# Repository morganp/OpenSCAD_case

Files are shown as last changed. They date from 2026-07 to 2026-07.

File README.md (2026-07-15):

# OpenSCAD_case

Parametric case/box library, plain OpenSCAD, no external libraries beyond the
[OpenSCAD_hinge](https://github.com/morganp/OpenSCAD_hinge) dependency (auto-fetched by
[OpenSCAD-gui](../OpenSCAD-gui) via its `// @github:` tag). Loadable standalone in real
OpenSCAD and in the browser.

## hinged_box — two-tray hinged box with pinned hinges and a snap latch

A body tray and a lid tray joined by real pinned hinges across the back seam, with an
alignment lip on the body rim and a snap latch on the front. Two printed parts, no supports;
each part carries its own fused hinge leaf, and a pin dropped through the knuckles finishes
the assembly. Far more robust than a living/flex hinge, and the pin is replaceable if it
ever wears.

| Print pose | Closed (assembly check) |
|---|---|
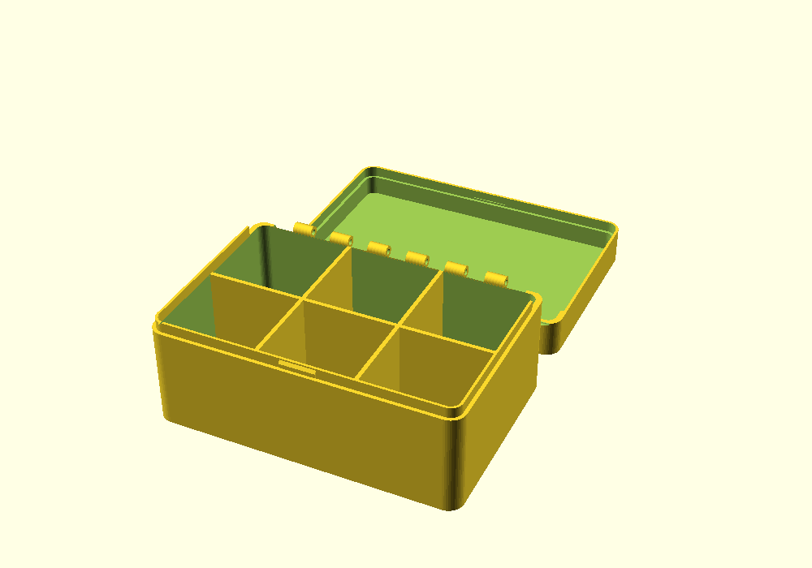
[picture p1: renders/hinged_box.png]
hinged_box print pose
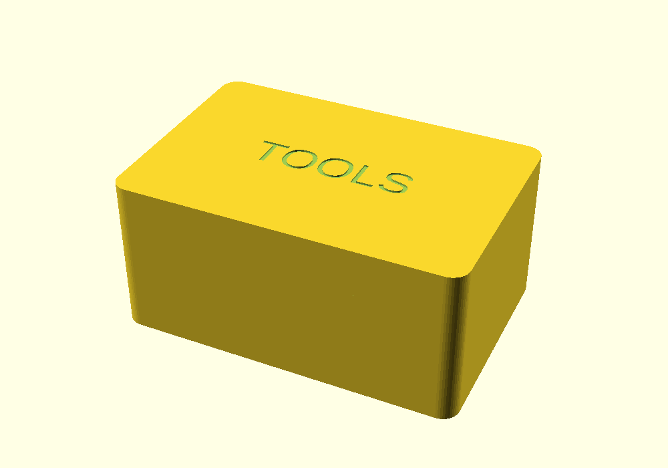
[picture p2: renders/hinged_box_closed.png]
hinged_box closed
|  |  |

**[▶ Open in SCAD Studio](https://lizard-spock.co.uk/openscad-gui/?github=morganp/OpenSCAD_case/examples/hinged_box_demo.scad)** —
view this example in the browser, no install; the library (and its hinge dependency) load automatically.

```openscad
include <case_library.scad>

hinged_box(
    length = 120, width = 80, height = 40,
    lid_depth = 15,
    div_x = 2, div_y = 1,
    lid_text = "TOOLS"
);
```

### Hinge types

| `hinge_type` | Hinge | Pin |
|---|---|---|
| `"piano"` (default) | One continuous knuckle hinge across the back seam — even load spread, sturdiest | 1.75mm filament offcut |
| `"knuckle"` | `hinge_count` discrete knuckle hinges — lighter, classic look | 1.75mm filament offcut |
| `"crate"` | Chunky raised-lug crate hinges, lid opens past 180° — the rugged/ammo-box look | 4mm rod, or the printed pins emitted beside the parts |
| `"flush"` | Fully hidden hinge: pivot buried mid-wall, knuckle OD = wall thickness, zero protrusion; works down to 2mm walls; lid opens flat to 180° | 0.8mm rod/wire, slid in along the seam; far end blind, printed cap glues into the first knuckle |

The hinge geometry itself comes from
[OpenSCAD_hinge](https://github.com/morganp/OpenSCAD_hinge)'s `piano_hinge` /
`knuckle_hinge` / `crate_hinge` / `flush_knuckle_hinge`, emitted one leaf at a time
(`parts="leaf1"/"leaf2"`) so each printed part gets its own fused leaf.

### Flush (hidden) hinge variation

`hinge_type="flush"` buries the pivot in the middle of the back wall: the knuckles are sized
to the wall thickness and nothing protrudes past the outer face — the hinge reads as a plain
seam with a knuckle line inside a cove. Works down to 2mm walls (2mm knuckles). The hinge is
`flush_knuckle_hinge`: each leaf plate is as thick as the wall and runs right up to the axis,
with a scallop along its inner edge that nests the other leaf's knuckles at close radial
tolerance, so it closes flat and the lid opens flat to a full 180°. Outside the hinge span
the rims still carry a cove relief to swing past the buried axis.

The pin is a 0.8mm rod or wire (`pin_d` auto). The axis line runs through open air behind
the rounded back corner, so the rod slides straight in along the seam with no tunnel; a plug
fused inside the far knuckle makes that end blind so the rod cannot walk out, and the small
printed cap (emitted beside the parts) glues into the first knuckle's bore to close the
entry. Cap and plug are coaxial with the pivot, so the swing never touches them. The
`echo()` output states the rod cut length.

| Print pose | Closed |
|---|---|
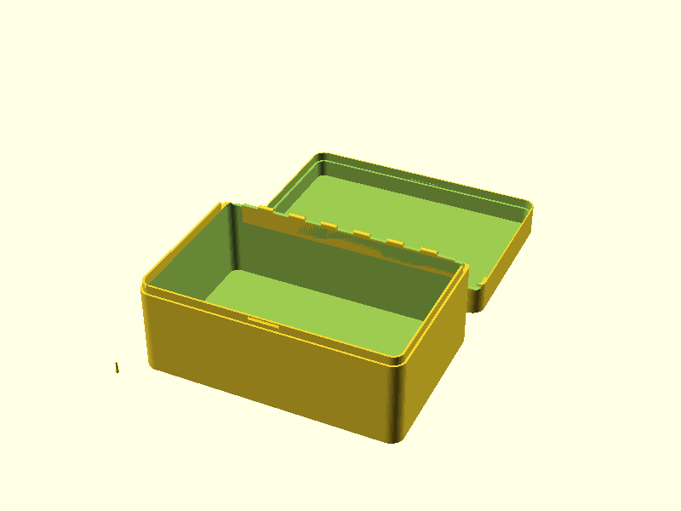
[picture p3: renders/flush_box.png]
flush_box print pose
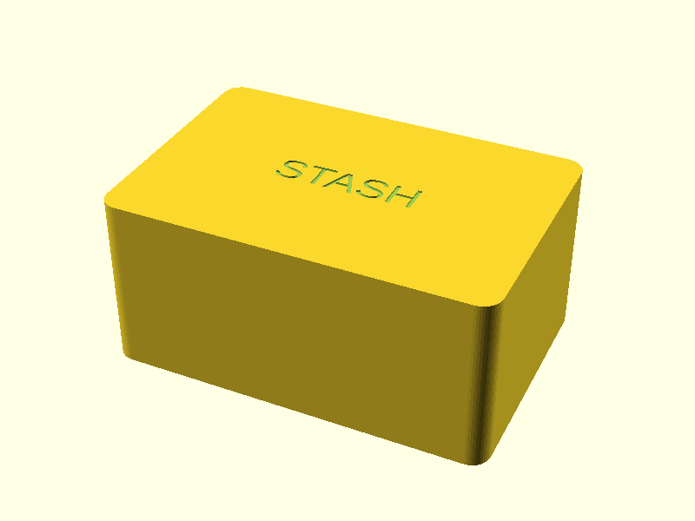
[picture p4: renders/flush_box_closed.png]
flush_box closed
|  |  |

**[▶ Open in SCAD Studio](https://lizard-spock.co.uk/openscad-gui/?github=morganp/OpenSCAD_case/examples/flush_box_demo.scad)**

### Rugged box variation

Set `hinge_type="crate"` and `ribs > 0` for the rugged-crate look: vertical ribs run up the
front wall, across the seam, and over the lid top; crate hinges hang on the back.

```openscad
hinged_box(
    length = 140, width = 90, height = 45, lid_depth = 20,
    hinge_type = "crate", hinge_count = 2, hinge_len = 32,
    ribs = 4
);
```

| Print pose | Closed |
|---|---|
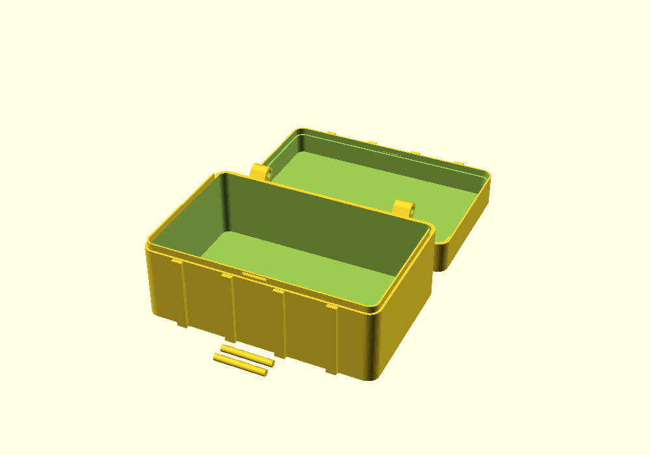
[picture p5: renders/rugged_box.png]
rugged_box print pose
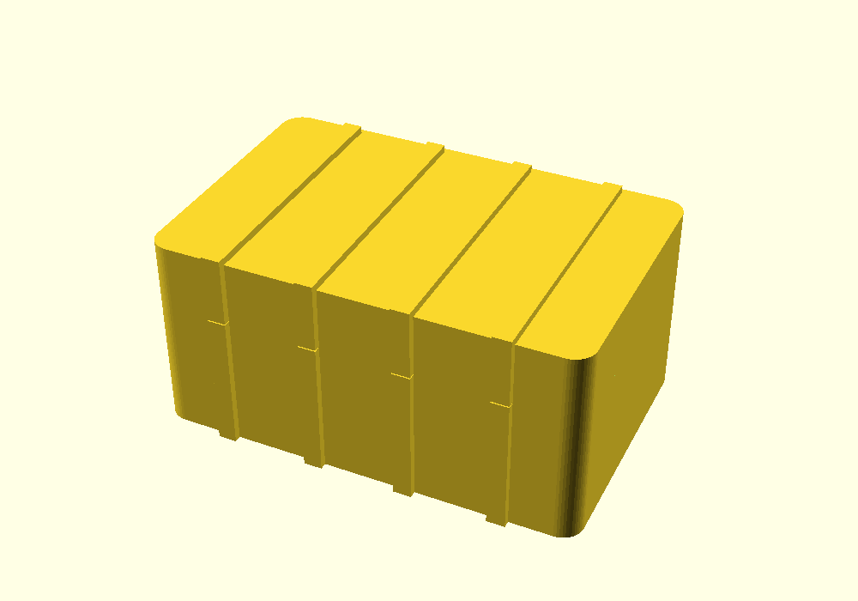
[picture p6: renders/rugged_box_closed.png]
rugged_box closed
|  |  |

**[▶ Open in SCAD Studio](https://lizard-spock.co.uk/openscad-gui/?github=morganp/OpenSCAD_case/examples/rugged_box_demo.scad)**

### How it prints and assembles

`pose="print"` (default) lays both parts flat on the bed: the body upright, the lid beyond
it in +Y opening up. The hinge leaves are recessed flush into the back walls (leaf thickness
is clamped below the wall, leaf width below the lid depth), so only the barrel sits proud of
the back face; the mating rims are notched around each other's knuckles, and a half-round
groove along the seam gives the pin a clear entry path. Print, then mate the hinge knuckles
and slide the pin in along the seam groove — a length of 1.75mm filament for piano/knuckle
(melt-mushroom the ends to captivate it), a 4mm rod or the printed pins for crate. The lid
then folds over; the lip registers it and the front ridge snaps into the groove inside the
lid wall. The lip is the inner portion of the body wall carried up past the seam
(`min(1, wall/2)` thick, solid with the wall), and the lid wall is rebated to match — a
shiplap seam rather than a separate ring.

`pose="closed"` renders the assembled box (pins shown in place) for checking fit,
proportions, and lid text before printing.

Print settings (slicer profile, not module parameters): 0.2mm layer height, 3–4 walls, PLA
or PETG. The small piano/knuckle barrel overhangs on the back faces print fine without
supports; the chunky crate lugs stick out further and may want supports or tuned bridging.

| Parameter | Default | Meaning |
|---|---|---|
| `length` | 120 | Outer footprint, X |
| `width` | 80 | Outer footprint, Y |
| `height` | 40 | Body tray **outer** height, bed to seam, includes the floor wall |
| `lid_depth` | 15 | Lid tray **outer** height above the seam, includes the lid top wall |
| `wall` | 2.4 | Wall thickness |
| `corner_r` | 6 | Outer corner rounding radius |
| `div_x` | 0 | Internal dividers splitting `length` (walls run along Y) |
| `div_y` | 0 | Internal dividers splitting `width` (walls run along X) |
| `div_thickness` | 1.6 | Divider wall thickness |
| `hinge_type` | "piano" | `"piano"` / `"knuckle"` / `"crate"` / `"flush"` |
| `hinge_count` | 2 | Number of discrete hinges (knuckle/crate) |
| `hinge_len` | 30 | Leaf length along X per discrete hinge (knuckle/crate) |
| `hinge_margin` | 8 | Hinge inset from each end along X |
| `knuckle_od` | 0 (auto) | Piano/knuckle barrel OD; auto = `max(5, 2*wall)`; flush forces `wall` |
| `pin_d` | 0 (auto) | Hinge pin diameter; auto = 1.75 (filament), 4 for crate, 0.8 for flush |
| `pin_clearance` | 0.25 | Radial pin-to-bore clearance |
| `leaf_thickness` | 2 | Hinge leaf/strap thickness, recessed into the back walls (clamped to `wall - 0.4`) |
| `lip_h` | 4 | Alignment lip height above the seam (clamped to fit inside the lid cavity) |
| `lid_clearance` | 0.3 | Radial clearance between the wall-lip and the rebated lid wall |
| `latch_w` | 14 | Snap latch width, centered on the front |
| `latch_bump` | 0.8 | Snap ridge protrusion from the lip face |
| `ribs` | 0 | Rugged-look vertical ribs on the front wall and over the lid top |
| `rib_w` | 0 (auto) | Rib width; auto = `2.5*wall` |
| `rib_depth` | 0 (auto) | Rib protrusion; auto = `wall` |
| `lid_text` | "" | Text on the lid's outer top face |
| `lid_text_size` | 10 | Lid text size |
| `lid_text_depth` | 0.6 | Engrave/emboss depth |
| `lid_text_emboss` | false | true = raised text (prints face-down — prefer the default deboss on FDM) |
| `pose` | "print" | `"print"` = parts flat on the bed, `"closed"` = assembled preview |
| `fn` | 48 | Circle resolution |

**Dimensions are outer.** All four size parameters are external, walls included. The
`echo()` output reports the internal numbers at render time: internal footprint
`(length-2*wall) x (width-2*wall)`, body cavity depth `height-wall`, and closed
floor-to-lid clearance `height+lid_depth-2*wall`.

**Fit notes:** `lid_clearance`, `latch_bump`, and `pin_clearance` are best-effort starting
points, not tuned to a specific printer/material — check on a test print. Lid text sits on
the outer top face, which prints against the bed; the default debossed text prints fine
face-down, raised text does not. Ribs and lid text both occupy the lid top, so debossed text
carves through any ribs it crosses (stencil look) — drop one or the other if that's not
wanted.

## Regenerating previews

```sh
openscad -o renders/<name>.png        --imgsize=1000,700 --autocenter --viewall examples/<name>_demo.scad
openscad -o renders/<name>_closed.png --imgsize=1000,700 --autocenter --viewall -D 'pose="closed"' examples/<name>_demo.scad
```

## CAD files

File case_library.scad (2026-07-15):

// case_library.scad
// Parametric case/box library — plain OpenSCAD, no external includes (see hinge include below
// for the one exception: it pulls in ../OpenSCAD_hinge/hinge_library.scad, tagged so
// OpenSCAD-gui can auto-fetch it too).
//
// @github: morganp/OpenSCAD_hinge
include <../OpenSCAD_hinge/hinge_library.scad>

// ---------------------------------------------------------------------------
// Internal helpers
// ---------------------------------------------------------------------------

module _rounded_rect(l, w, r, fn=48) {
    rr = min(r, l/2, w/2);
    hull() {
        for (cx = [rr, l-rr]) for (cy = [rr, w-rr])
            translate([cx, cy]) circle(r=rr, $fn=fn);
    }
}

module _box_shell(length, width, height, wall, corner_r, fn) {
    difference() {
        linear_extrude(height=height) _rounded_rect(length, width, corner_r, fn);
        translate([wall, wall, wall])
            linear_extrude(height=height) // overshoots the top on purpose -> open top
                _rounded_rect(length - 2*wall, width - 2*wall, max(0.1, corner_r - wall), fn);
    }
}

module _dividers(length, width, height, wall, div_x, div_y, div_thickness) {
    inner_l = length - 2*wall;
    inner_w = width  - 2*wall;
    div_h   = height - wall; // flush with the rim; the lid tray gives headroom above the seam
    if (div_x > 0) {
        step = inner_l / (div_x + 1);
        for (i = [1:div_x])
            translate([wall + step*i - div_thickness/2, wall, wall])
                cube([div_thickness, inner_w, div_h]);
    }
    if (div_y > 0) {
        step = inner_w / (div_y + 1);
        for (i = [1:div_y])
            translate([wall, wall + step*i - div_thickness/2, wall])
                cube([inner_l, div_thickness, div_h]);
    }
}

// 45-degree chamfer cutter along the back edge at y=w, z=z: a diamond prism whose
// cross-section is centered on the edge line, so subtracting it from either the body
// (solid below/inside) or the lid (solid above/inside) chamfers that part's rim edge.
module _hb_edge_chamfer(l, w, z, ch) {
    s = ch * 1.4143;
    translate([-1, w, z])
        rotate([45, 0, 0])
            translate([0, -s/2, -s/2])
                cube([l + 2, s, s]);
}

// Alignment/dust lip: the inner portion of the body wall carried up past the seam, flush
// with the wall's inner face — a shiplap joint with the rebated lid wall, so the lip is
// solid wall material, not a separate ring. Cut short of the back edge so nothing sits
// inside the hinge swing zone.
module _hb_lip(l, w, wall, lip_t, z, lip_h, y_max, corner_r, fn) {
    o = wall - lip_t;
    intersection() {
        translate([0, 0, z - 0.5]) // overlaps the wall top so lip and wall fuse
            linear_extrude(height=lip_h + 0.5)
                difference() {
                    translate([o, o])
                        _rounded_rect(l - 2*o, w - 2*o, max(0.1, corner_r - o), fn);
                    translate([wall, wall])
                        _rounded_rect(l - 2*wall, w - 2*wall,
                                      max(0.1, corner_r - wall), fn);
                }
        translate([-1, -1, z - 1]) cube([l + 2, y_max + 1, lip_h + 3]);
    }
}

// Snap ridge on the lip's front outer face: square bottom face retains the closed lid,
// chamfered top face cams the lid wall outward as it slides down over the lip.
module _hb_bump(l, wall, lip_t, z, lip_h, latch_w, latch_bump) {
    bh = max(0.6, min(3, lip_h - 1.2));
    z0 = z + max(0.6, (lip_h - bh)/2);
    yo = wall - lip_t; // lip outer face
    hull() {
        translate([l/2 - latch_w/2, yo - 0.01, z0])
            cube([latch_w, 0.02, bh]);
        translate([l/2 - latch_w/2, yo - latch_bump, z0])
            cube([latch_w, latch_bump, max(0.4, bh - latch_bump*1.5)]);
    }
}

// Body tray in closed-assembly coordinates: tub + dividers + lip + snap ridge + front ribs.
module _hb_body(l, w, hb, wall, corner_r, div_x, div_y, div_t,
                lip_h, lip_t, c, lip_ymax, latch_w, latch_bump,
                rib_xs, rib_w, rib_d, back_ch, fn) {
    difference() {
        union() {
            _box_shell(l, w, hb, wall, corner_r, fn);
            _dividers(l, w, hb, wall, div_x, div_y, div_t);
            _hb_lip(l, w, wall, lip_t, hb, lip_h, lip_ymax, corner_r, fn);
            _hb_bump(l, wall, lip_t, hb, lip_h, latch_w, latch_bump);
            for (x = rib_xs)
                translate([x - rib_w/2, -rib_d, 0])
                    cube([rib_w, rib_d + 0.01, hb - 0.2]);
        }
        if (back_ch > 0)
            _hb_edge_chamfer(l, w, hb, back_ch);
    }
}

// Lid tray in closed-assembly coordinates (opening down, spanning z in [hb, hb+hl]):
// shell + lip rebate + front/top ribs + latch groove + lid text + hinge-clearance chamfer.
module _hb_lid(l, w, hb, hl, wall, corner_r, c, lip_t, lip_ymax,
               lip_h, latch_w, latch_bump,
               rib_xs, rib_w, rib_d, back_ch,
               txt, txt_size, txt_depth, txt_emboss, fn) {
    top   = hb + hl;
    bh    = max(0.6, min(3, lip_h - 1.2));
    z0    = hb + max(0.6, (lip_h - bh)/2);
    y_reb = wall - lip_t - c;   // rebated inner face over the lip engagement zone
    gd    = latch_bump - c;     // groove depth into the rebated wall
    difference() {
        union() {
            translate([0, 0, hb])
                difference() {
                    linear_extrude(height=hl) _rounded_rect(l, w, corner_r, fn);
                    translate([wall, wall, -0.05])
                        linear_extrude(height=hl - wall + 0.05)
                            _rounded_rect(l - 2*wall, w - 2*wall,
                                          max(0.1, corner_r - wall), fn);
                }
            for (x = rib_xs) {
                translate([x - rib_w/2, -rib_d, hb + 0.2])
                    cube([rib_w, rib_d + 0.01, hl - 0.2]);
                translate([x - rib_w/2, -rib_d, top - 0.01])
                    cube([rib_w, rib_d + w - 2, rib_d + 0.01]);
            }
            if (txt_emboss && len(txt) > 0)
                translate([l/2, w/2, top - 0.01])
                    linear_extrude(height=txt_depth + 0.01)
                        text(txt, size=txt_size, halign="center", valign="center");
        }
        // rebate: thin the lid wall's inner portion over the lip engagement zone so the
        // body's wall-lip slides up inside it (shiplap seam); restricted to where the lip
        // exists so the back wall around the hinge straps keeps full thickness
        intersection() {
            translate([0, 0, hb - 0.05])
                linear_extrude(height=lip_h + c + 0.15)
                    translate([y_reb, y_reb])
                        _rounded_rect(l - 2*y_reb, w - 2*y_reb,
                                      max(0.1, corner_r - y_reb), fn);
            translate([-1, -1, hb - 1])
                cube([l + 2, lip_ymax + c + 1.4, lip_h + c + 2]);
        }
        // latch groove in the rebated front wall face, mating the lip's snap ridge
        translate([l/2 - latch_w/2 - 0.3, y_reb - gd, z0 - 0.2])
            cube([latch_w + 0.6, gd + 0.01, bh + 0.5]);
        if (!txt_emboss && len(txt) > 0)
            translate([l/2, w/2, top - txt_depth])
                linear_extrude(height=txt_depth + 0.02)
                    text(txt, size=txt_size, halign="center", valign="center");
        if (back_ch > 0)
            _hb_edge_chamfer(l, w, hb, back_ch);
    }
}
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

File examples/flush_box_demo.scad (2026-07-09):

include <../case_library.scad>

pose = "print"; // override for an assembly check: openscad -D 'pose="closed"'

hinged_box(
    length     = 120,
    width      = 80,
    height     = 40,
    lid_depth  = 15,
    wall       = 2,   // flush hinge works down to 2mm walls: 2mm knuckles, 0.8mm rod pin

    corner_r   = 6,
    hinge_type = "flush",
    lid_text   = "STASH",
    pose       = pose
);

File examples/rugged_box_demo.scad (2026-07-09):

include <../case_library.scad>

pose = "print"; // override for an assembly check: openscad -D 'pose="closed"'

hinged_box(
    length      = 140,
    width       = 90,
    height      = 45,
    lid_depth   = 20,
    wall        = 2.4,
    corner_r    = 7,
    hinge_type  = "crate",
    hinge_count = 2,
    hinge_len   = 32,
    ribs        = 4,
    pose        = pose
);

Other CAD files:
examples/hinged_box_demo.scad

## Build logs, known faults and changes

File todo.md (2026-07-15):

# todo

## Done 2026-07-15 — flush case uses flush_knuckle_hinge

- [x] `hinge_type="flush"` now emits `flush_knuckle_hinge` from the hinge library instead of
      emulating a buried pivot with a thin-leaf `piano_hinge`. Full-thickness leaf plates run
      to the axis with scallop nesting, so the lid opens flat to 180 (was ~120). Rugged
      ("crate") path unchanged. Pin/cap/blind-plug retention scheme unchanged (0.8mm rod).

## Done 2026-07-09 — hinged_box redesign (two-tray, pinned hinges)

Review found the old flat-fold design unprintable at all (the open-pose lid panel floated at
`z = height - wall` with nothing beneath it), on top of the fold-geometry bugs listed on
2026-07-07. Rebuilt as two trays (body + lid) with pinned hinges fused across the back seam:

- [x] Default hinge now robust: `hinge_type="piano"` knuckle hinge, 1.75mm filament pin.
- [x] Hinge selectable: `"piano"` / `"knuckle"` (discrete, `hinge_count`) / `"crate"`.
- [x] Crate hinge supported for the rugged look; printed 4mm pins emitted beside the parts.
- [x] Rugged box variation: `ribs` / `rib_w` / `rib_depth` params (front wall + over lid top).
- [x] `pose="closed"` assembled preview (would have caught the old fold bugs).
- [x] Alignment lip + front snap latch (ridge on lip, groove inside lid wall), chamfered
      cam faces, correct engagement depths.
- [x] Separate lid depth (`lid_depth`) — the obloid two-tray model.
- [x] Hinge count 1/2/3 via `hinge_count` (knuckle/crate).
- [x] `echo()` print-dimension + pin readout.
- [x] Lid text on the outer top face (was on the inner face in the old design).
- [x] Box now centered on the XY origin per repo conventions (was corner-at-origin).
- [x] Living-hinge variant dropped: with a top-edge fold axis the open lid can never rest on
      the bed unless body and lid depths are equal, so the old print-in-place promise was
      geometrically false. All 2026-07-07 fold-bug items are moot with the redesign.
- [x] Hinge library: `parts="leaf1"/"leaf2"` on knuckle/piano/crate hinges (+ README rows),
      `screws_per_leaf=0` guard on crate_hinge.

## Open

- [ ] Print-in-place clamshell variant (equal-depth halves hinged at the top rim — the only
      layout where a fold-flat living hinge is actually printable); needs a
      webs-on-one-side option (`groove_side`) in `living_hinge`.
- [ ] Diagonal dividers: none / single diagonal / diagonal X.
- [ ] Opener tabs (thumb notch), count auto/1/2.
- [ ] Multi-color 3MF: box / lid / text colors (`color()` exports to 3MF in recent
      OpenSCAD); "color text flush" variant in addition to deboss/emboss.
- [ ] Rough weight estimate in the `echo()` readout.
- [ ] `inner = true` flag on hinged_box reinterpreting length/width/height/lid_depth as
      internal dimensions (convert once at the top: `l = inner ? length + 2*wall : length`
      etc.) — obloid-style tools offer this.
- [ ] Draw-latch / toggle-clasp option for the rugged box (snap lip is the only latch now).
- [ ] Optional side ribs + back ribs that dodge the hinge strap positions.
- [ ] Lip top-edge lead-in chamfer for easier closing.
- [ ] Verify OpenSCAD-gui loads the new files (list comprehensions, `parts` param).

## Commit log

2026-07-07 Init OpenSCAD_case project with CLAUDE.md
    Vanilla OpenSCAD case/box library, no BOSL2 (must load in OpenSCAD-gui),
    reuses ../OpenSCAD_hinge/hinge_library.scad for lid hinges.
2026-07-07 Add hinged_box: print-in-place snap-fit box with dividers, rounded corners, lid text
    Vanilla OpenSCAD, box+living_hinge+lid print as one piece, fold closed by
    hand, snaps shut on a latch opposite the hinge. Reuses hinge_library.scad
    from ../OpenSCAD_hinge (relative include + @github tag for OpenSCAD-gui).
    Independent implementation matching the feature set of
    obloid.app/tools/hinged-box (size/depth, dividers, rounded corners, lid
    text, Bambu/Orca-ready), not a copy of that site's code.
    Also documents the new // @github: owner/repo import-tag convention in
    CLAUDE.md.
    [case_library.scad, hinged_box_demo.scad]
2026-07-07 README: add Open in SCAD Studio deep link for the hinged_box example
2026-07-09 Redesign hinged_box as two-tray box with pinned hinges and rugged variant
    The old flat-fold living-hinge design was unprintable: the open-pose lid
    panel floated at z = height - wall with nothing beneath it, on top of the
    fold-geometry bugs already logged in todo.md. Rebuild as a body tray plus
    lid tray joined by pinned hinges fused across the back seam, printed as
    two supportless parts and assembled by dropping a pin through the
    knuckles.
    - hinge_type = "piano" (default, filament pin) | "knuckle" (discrete,
    hinge_count/hinge_len) | "crate" (raised-lug rugged look, 4mm rod or
    printed pins emitted beside the parts); living variant dropped
    - ribs/rib_w/rib_depth for the rugged-box look: ri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
    [case_library.scad, hinged_box_demo.scad, rugged_box_demo.scad]
2026-07-09 Clamp alignment lip height to the lid cavity depth
    lip_h was used as-is, so a lid shallower than the default 4mm lip (plus
    wall and clearance) would land on the lip instead of closing. The
    effective lip height is now min(lip_h, lid_depth - wall - lid_clearance),
    floored at 0.8, and the snap ridge/groove height is floored at 0.6 so
    very shallow lips keep valid latch geometry.
    [case_library.scad]
2026-07-09 Recess hinge leaves flush into the box and lid walls
    Leaves previously sat proud on the back faces as external straps. The
    mount plane is now sunk by the leaf thickness (clamped to wall - 0.4) so
    the plates merge into the walls with the outer face flush, leaving only
    the barrel proud. Leaf width is clamped below the lid depth so straps
    never poke past a shallow lid; the crate strap thickness follows the
    same clamp instead of exceeding the wall.
    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
    [case_library.scad]
2026-07-09 Document height/lid_depth as outer dimensions; echo internal clearances
    height and lid_depth include their walls, which the docs did not make
    explicit. Both are now labeled outer in the docstring and README, with a
    note that all four size parameters are external. A second echo() line
    reports the internal numbers at render time: internal footprint, body
    cavity depth, and closed floor-to-lid clearance. An inner=true flag to
    accept internal dimensions directly is logged in todo.md.
    [case_library.scad]
2026-07-09 Rebuild the alignment lip as a shiplap seam cut into the walls
    The lip ring was inset wall + clearance from the outer face while the
    wall's inner face sits at wall, leaving it floating 0.3mm inboard over
    the open interior - a separate unsupported body that only happened to be
    propped up by dividers in the demo.
    The lip is now the inner portion of the body wall carried up past the
    seam (min(1, wall/2) thick, flush with the wall's inner face, fused into
    the wall top), and the lid wall is rebated lip + clearance deep over the
    lip engagement zone so the wall-lip slides up inside it. The rebate is
    restricted to the lip's footprint so the back wall keeps full thickness
    around the hinge straps. Th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
    [case_library.scad]
2026-07-09 Add flush hinge type: pivot buried mid-wall, zero protrusion
    hinge_type="flush" centers the pivot inside the back wall at the seam
    with the knuckle OD forced to the wall thickness, so nothing protrudes
    past the outer face. Full-width piano-style knuckles; anchor plates fill
    the wall's inner half flush with the interior face. A full-length cove
    relief (radius = wall) along the seam lets the rims swing past the
    buried axis - anything solid through a mid-wall pivot must be a coaxial
    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
    [case_library.scad, flush_box_demo.scad]
2026-07-09 Flush hinge: 0.8mm rod pin, blind far end, glue-in cap, 2mm walls
    The flush hinge now targets a 0.8mm rod/wire pin and works at 2mm walls
    (2mm knuckles), with a tighter 0.15 pin clearance to keep skin around
    the bore. Retention is captive: a plug fused inside the far knuckle
    makes that end blind so the rod cannot slide out, and a small printed
    cap (emitted beside the parts) glues its stem into the first knuckle's
    bore behind the rod. Both are coaxial with the pivot, so the swing never
    touches them. The rod slides in along the seam - the axis line runs
    through open air behind the rounded back corner, so no entry tunnel is
    needed - and the echo() reports the cut length.
    The seam cove is also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
    [case_library.scad, flush_box_demo.scad]
2026-07-15 Flush case: use flush_knuckle_hinge instead of thin-leaf piano emulation
    Route hinge_type="flush" to the hinge library's flush_knuckle_hinge:
    full-thickness leaf plates run to the axis with scallop nesting, so the
    lid now opens flat to 180 degrees (was ~120). Knuckle count derived at
    ~8mm pitch, forced odd so the lid leaf owns both ends and the blind
    plug + glue-in cap rod retention is unchanged. Crate/rugged path
    untouched. Update README, echo text, and flush renders.
    [case_library.scad]
